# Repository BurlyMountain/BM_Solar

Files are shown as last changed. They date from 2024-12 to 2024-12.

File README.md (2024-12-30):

# BM_Solar 

This little PCB uses a Texas Instruments bq25185 chip to act as a solar charge controller and battery managment system for single cell Lithium Polymer, Lithium Ion, or Lithium Phosphate batteries.

It was designed specifically to act as a hat for Waveshare RP2040-LoRa boards. It is the same footprint and will solder directly on the backside of a RP2040-LoRa board.

*(Though it was designed for the RP2040-LoRa, it will work with any other board that can run off of a 4.5V input.)*

# Specifications

- 1A max charge rate (limited by solar input)
    - *can be adjusted by changing the value of R2*
- Stable 4.5V output to a device
- 3-18V solar input voltage
- Automatically switches to battery power once solar drops below 3V
- Uses a 10kOhm thermistor to stop charging below 0F/32C in order to prevent damage to the battery
- Much more efficient than built in solar charging on most Meshtastic boards with near MPPT efficiency
- Selectable charge profile between LiPo/LiIon and LFP with an easy jumper
- built in voltage divider for battery voltage monitoring

---

In the near future this board will be for sale on https://burlymountan.com

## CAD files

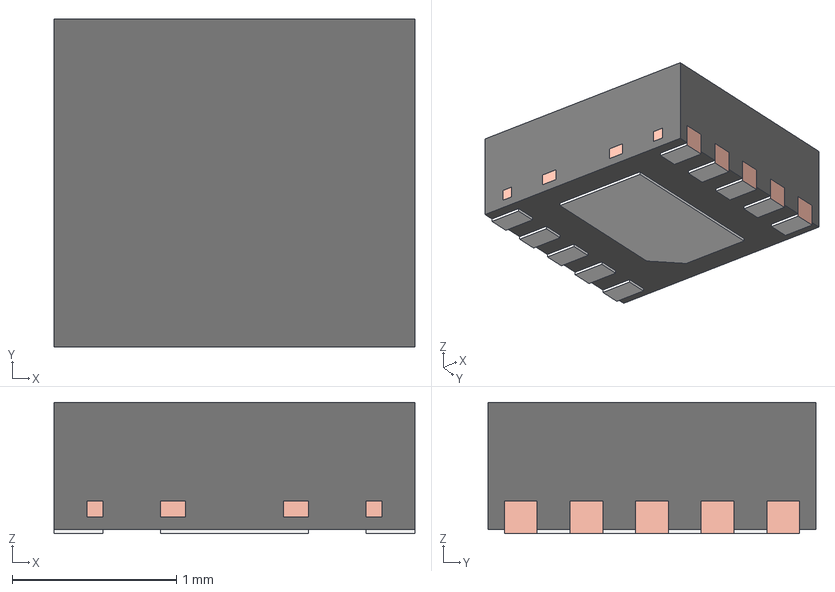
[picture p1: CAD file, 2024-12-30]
BQ25185DLHR/DLH0010A.stp
2.20 x 2.00 x 0.8 mm
BODY-SON
FRAME-DLH0010A
PIN1-ID

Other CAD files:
BQ25185DLHR/DLH0010A.stl

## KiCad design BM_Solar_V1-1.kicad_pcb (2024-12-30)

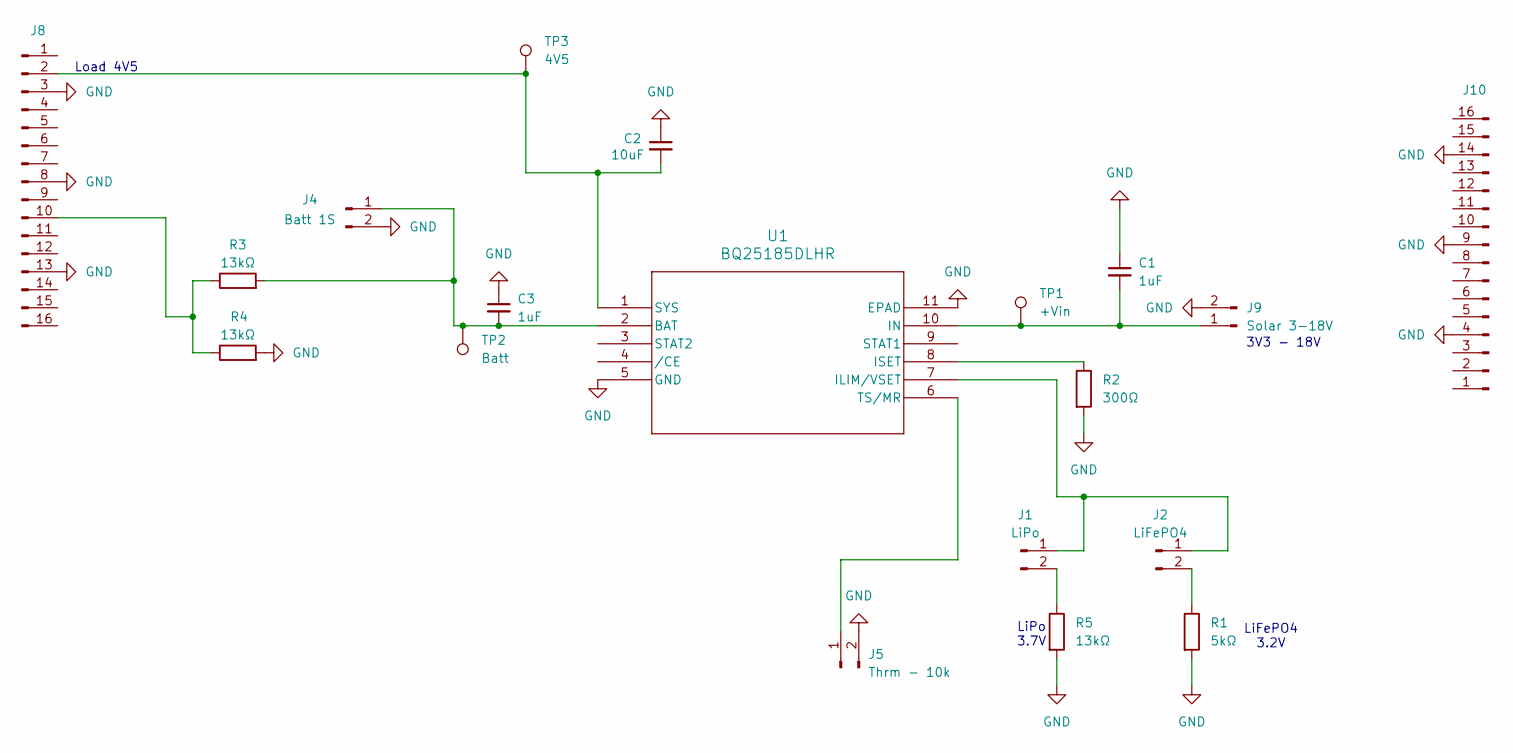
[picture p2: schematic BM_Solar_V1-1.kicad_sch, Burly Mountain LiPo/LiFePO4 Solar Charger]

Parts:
C1, C3: 1uF; C_0805_2012Metric
C2: 10uF; C_0805_2012Metric
J1: LiPo; PinHeader_1x02_P2.54mm_Vertical
J2: LiFePO4; PinHeader_1x02_P2.54mm_Vertical
J4: Batt 1S; JST_PH_S2B-PH-K_1x02_P2.00mm_Horizontal
J5: Thrm - 10k; SolderWire-0.5sqmm_1x02_P4.6mm_D0.9mm_OD2.1mm
J8, J10: Conn_01x16_Pin; PinHeader_1x16_P2.54mm_Vertical
J9: Solar 3-18V; JST_PH_S2B-PH-K_1x02_P2.00mm_Horizontal
R1: 5kΩ; R_0805_2012Metric
R2: 300Ω; R_0805_2012Metric
R3, R4, R5: 13kΩ; R_0805_2012Metric
TP1: +Vin; TestPoint_Pad_D1.0mm
TP2: Batt; TestPoint_Pad_D1.0mm
TP3: 4V5; TestPoint_Pad_D1.0mm
U1: BQ25185DLHR; WSON10_DLH_TEX

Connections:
GND: C1.1, C2.1, C3.1, J4.2, J5.2, J8.3, J8.8, J8.13, J9.2, J10.4, J10.9, J10.14, R1.2, R2.2, R4.2, R5.2, U1.5 (GND), U1.11 (EPAD)
unnamed: J1.1, J2.1, U1.7 (ILIM/VSET)
unnamed: J1.2, R5.1
unnamed: J2.2, R1.1
unnamed: C3.2, J4.1, R3.2, TP2.1, U1.2 (BAT)
unnamed: J5.1, U1.6 (TS/MR)
unnamed: C2.2, J8.2, TP3.1, U1.1 (SYS)
unnamed: J8.10, R3.1, R4.1
unnamed: C1.2, J9.1, TP1.1, U1.10 (IN)
unnamed: R2.1, U1.8 (ISET)

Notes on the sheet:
Load 4V5
3V3 - 18V
LiFePO4 3.2V
LiPo 3.7V

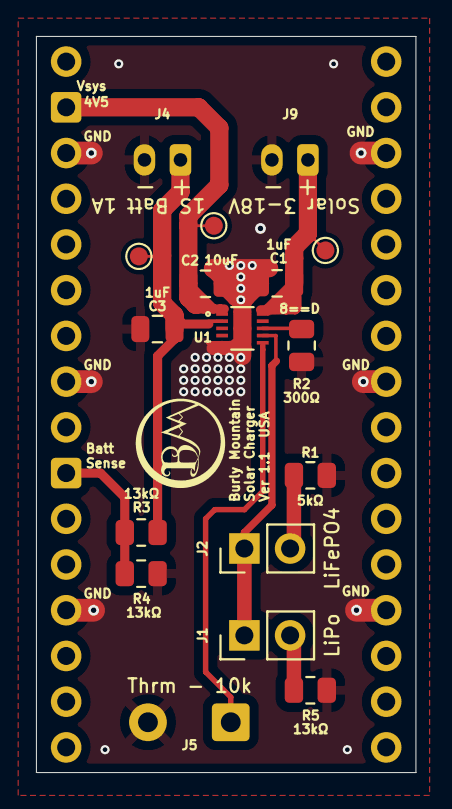
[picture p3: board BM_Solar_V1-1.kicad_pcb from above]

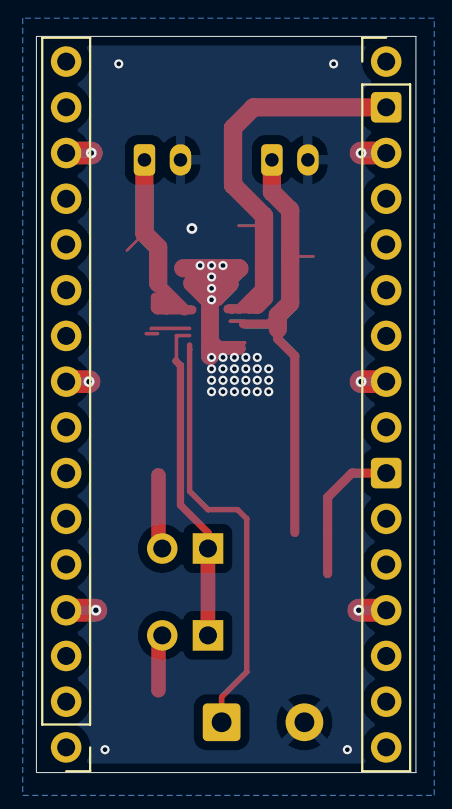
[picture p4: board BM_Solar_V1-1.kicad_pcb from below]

Board: 2 copper layers, 21.1 x 40.9 mm, 19 parts (2 on the bottom side), 10 nets.

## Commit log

2024-12-30 First commit - V1.1 board
    [DLH0010A.stl, DLH0010A.stp, bq25185-solar-lifep04_V1_1.kicad_pcb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]
2024-12-30 Changed name from bq25185-solar-lifep04 to BM_Solar_V1-1
    [BM_Solar_V1-1.kicad_pcb, BM_Solar_V1-1.kicad_sch]
